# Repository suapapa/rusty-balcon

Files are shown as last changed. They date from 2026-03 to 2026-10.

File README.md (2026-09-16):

# Rusty Balcon

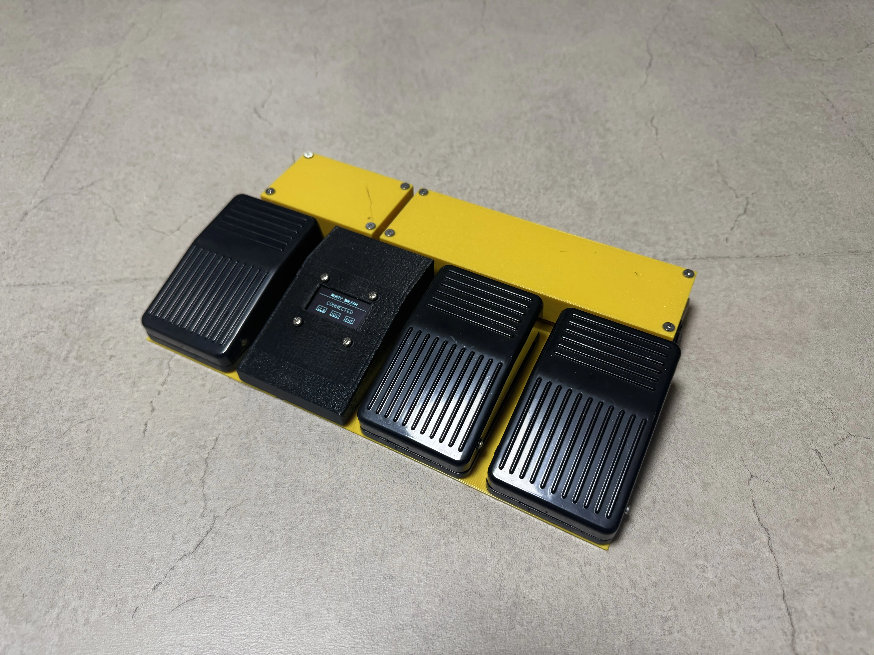
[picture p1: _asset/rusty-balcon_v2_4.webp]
Rusty Balcon


**Rusty Balcon** is a Rust-based firmware for an ESP32-H2 acting as a 3-key barebones Bluetooth (BLE) keyboard. It leverages the standard library (`std`) and `esp-idf-svc` for a robust development environment, implementing a HID Keyboard profile using the NimBLE stack via `esp32-nimble`.

## Hardware Build

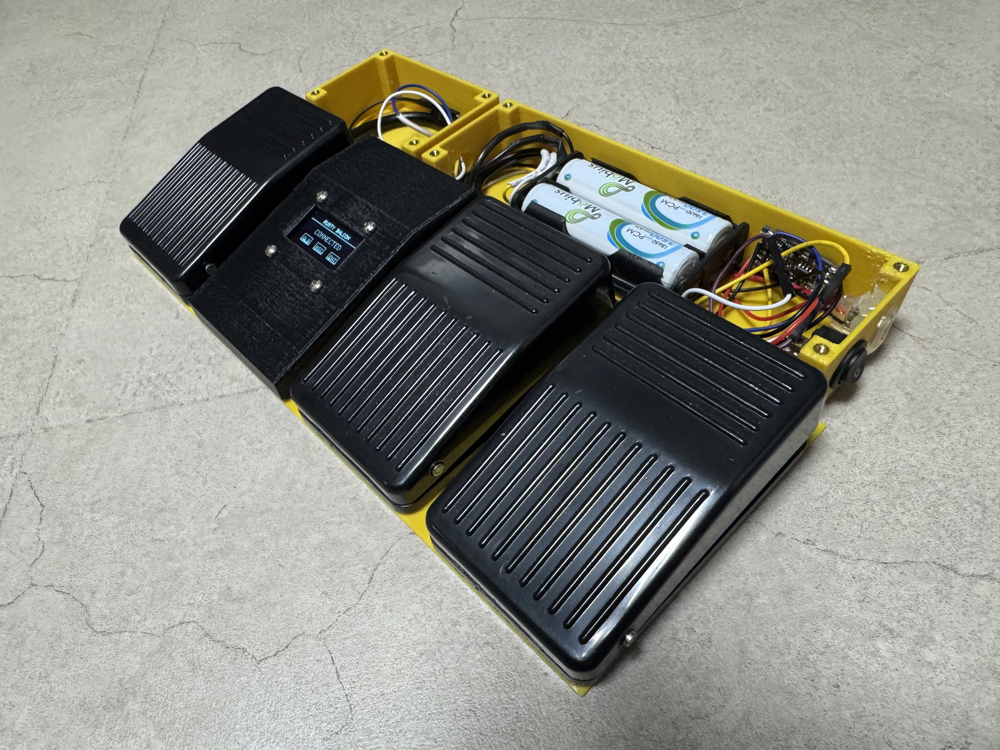
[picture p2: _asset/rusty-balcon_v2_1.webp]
Assembled build with internals

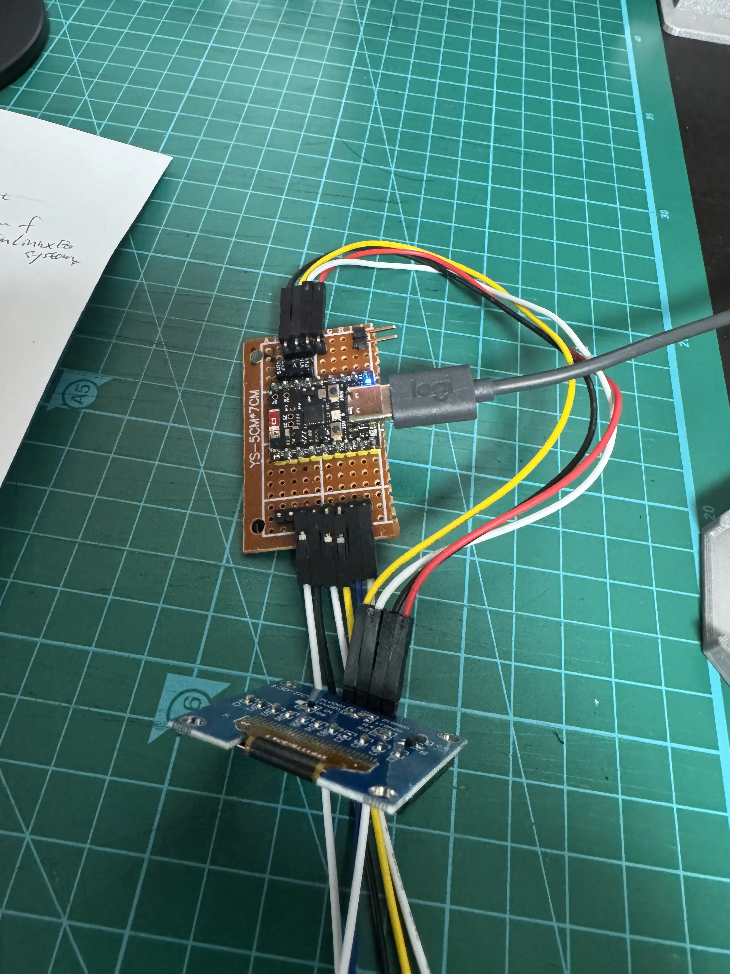
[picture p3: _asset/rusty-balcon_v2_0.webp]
Electronics prototype

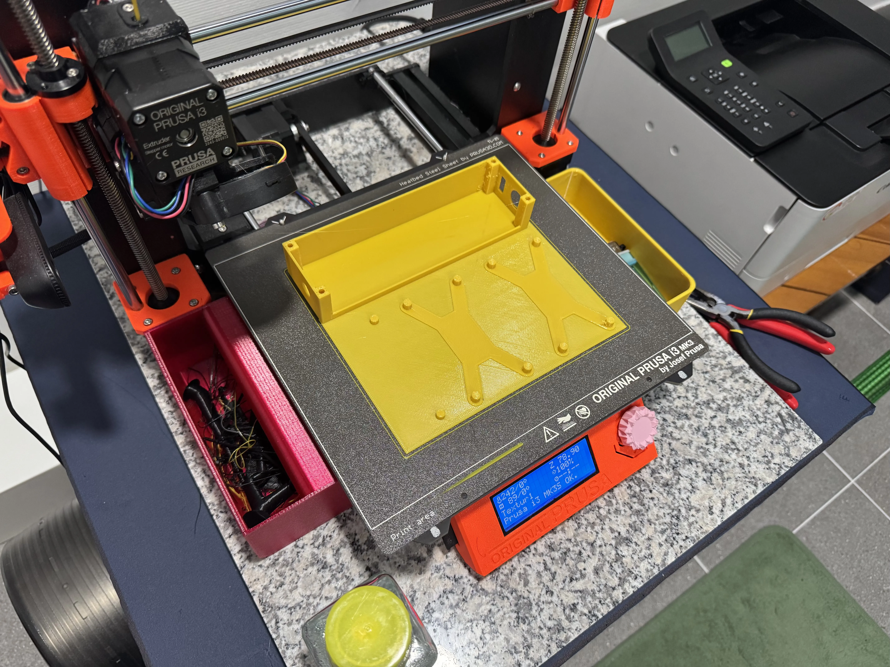
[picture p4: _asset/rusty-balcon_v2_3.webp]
3D-printed enclosure


## Hardware Configuration

- **Microcontroller**: ESP32-H2
  - Module reference: [esp32-h2-supermini-kicad](https://github.com/Zektopic/esp32-h2-supermini-kicad)
- **Inputs**: 3 Push Buttons (RTC GPIOs 7–14 required for deep-sleep EXT1 wakeup)
  - Key 1: `GPIO13` (Internal Pull-Up) → Globe 🌐 (Consumer AC Keyboard Layout Select)
  - Key 2: `GPIO11` (Internal Pull-Up) → Voice Command (Consumer Control) or Escape (ESC) Key (Toggleable)
  - Key 3: `GPIO12` (Internal Pull-Up) → Enter key
- **Display**: SH1106 128x64 OLED (I2C)
  - SDA: `GPIO4`
  - SCL: `GPIO5`

## Features

- **Bluetooth HID Keyboard**: Acts as a standard BLE keyboard using the NimBLE stack. Identifies as an Apple Magic Keyboard mock for best compatibility with macOS/iOS.
- **OLED Status Display**: Shows current device state on a 128x64 OLED screen with real-time key press visualization and dynamic Key 2 label (`MIC` / `ESC`).
- **Key 2 Mode Switching (Voice ↔ ESC)**: Hold **Key 1 (Globe) + Key 2** simultaneously for 5 seconds to toggle Key 2 function between **Voice Command (`MIC`)** and **Escape key (`ESC`)**. The selected mode is persisted to NVS (Non-Volatile Storage) across reboots and deep sleep.
- **Power Management**:
  - Display blanks after **30 seconds** of inactivity.
  - While **Connected**, stays awake (display off only) so keys remain instantly responsive.
  - Enters Deep Sleep after **30 minutes** of inactivity **only when Idle** (disconnected). Wakes on button press (GPIO13, GPIO11, or GPIO12 via EXT1).
- **Wakeup Key Replay**: The button press that wakes the device from deep sleep is remembered and automatically replayed 500ms after BLE reconnects (respecting the current Key 2 mode), so the keypress is never lost.
- **Pairing Mode**: Hold **Globe + Enter** simultaneously for 5 seconds to clear all bonds and enter pairing mode. OLED shows `>> PAIRING <<` while advertising for a new host.

## Device States

| Display Text | Meaning |
|---|---|
| `IDLE` | Not connected, advertising |
| `RECONNECTING...` | Woke from deep sleep, waiting for BLE to reconnect |
| `>> PAIRING <<` | Pairing mode active (blinking) |
| `CONNECTED` | Connected to a host |
| `MODE: VOICE` | Key 2 set to Voice Command (MIC) |
| `MODE: ESC` | Key 2 set to Escape (ESC) key |

## Prerequisites

- [Rust Toolchain](https://rustup.rs/) (1.88+)
- [espup](https://github.com/esp-rs/espup) for ESP-RS toolchain setup
- [ldproxy](https://github.com/esp-rs/ldproxy) for linking
- `espflash` for flashing: `cargo install espflash`

## Build and Run

1. **Environment Setup**: Ensure your ESP-IDF environment is sourced (e.g., `. $HOME/export-esp.sh`).
2. **Build**:
   ```bash
   cargo build --release
   ```
3. **Flash and Run**:
   ```bash
   cargo run --release
   ```

## License

This project is open-source and available under the MIT License.

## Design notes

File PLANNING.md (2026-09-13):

# 2-Key Bluetooth Keyboard Implementation Plan

## Overview
This document outlines the plan for building a 2-key Bluetooth (BLE) keyboard using the ESP32-H2 microcontroller, `esp-hal` (version `~1.0`), and the `bleps` Bluetooth stack. The firmware will manage key inputs, Bluetooth HID over GATT (HOGP) communication, LED status indication, and aggressive power saving via Deep Sleep.

## 1. Hardware Definition
- **MCU**: ESP32-H2 (configured via `cargo` and `esp-hal`).
- **Inputs**: 2 Push Buttons connected to RTC-capable GPIO pins to allow waking up from deep sleep. Keys should use internal pull-up resistors (`Input<'d, PullUp>`).
- **Outputs**: 1 LED connected to a standard output GPIO pin.
- **Power**: Battery-operated, necessitating power-saving states.

## 2. State Machine Design
The device operates in one of the following main states:
1. **Idle / Disconnected**: Device is awake but not connected or advertising. LED is OFF.
2. **Pairing Mode**: Activated by holding both keys for 5 seconds. BLE advertising begins. LED blinks synchronously.
3. **Connected**: Device successfully established a BLE connection with a host (PC/Phone). LED stays ON solidly.
4. **Deep Sleep**: Entered after 5 minutes of total inactivity to conserve battery. Device halts execution and waits for a hardware interrupt (RTC wakeup) to reboot.

## 3. Core Features & Implementation Details

### A. Key Input & Long-Press Detection
- Use non-blocking timers (`esp_hal::time::Instant`) to track button states instead of blocking delays.
- Track variables for when both keys were first depressed.
- If both buttons remain depressed continuously for `5000` milliseconds, trigger the transition to **Pairing Mode**.
- Reset the hold timer immediately if either button is released.

### B. LED Status Control
- **State: Pairing**: Implement a periodic blink (e.g., toggle every 500ms) comparing `Instant::now()` against a stored timestamp.
- **State: Connected**: Assert the GPIO high to keep the LED ON.
- **State: Deep Sleep / Idle**: De-assert the GPIO to keep the LED OFF.

### C. Bluetooth & HID functionality (`bleps`)
- **BLE Stack**: Utilize `esp_radio::init()` and `BleConnector::new()` as the transport layer for `bleps`.
- **GATT Attributes**: Configure standard BLE HID attributes:
  - **Device Information Service** (0x180A): Manufacturer, PnP ID.
  - **Battery Service** (0x180F): Optional, but highly recommended for battery devices.
  - **Human Interface Device Service** (0x1812): Host the HID Report Map (defining the device as a typical Keyboard) and characteristic endpoints for Input Reports.
- **Advertising**: Start advertising with "Discoverable" flags and the HID appearance UUID when Pairing Mode is active.
- **Event Handling**: On a valid keypress (in the Connected state), generate an HID Report array mapping the respective key to a standard USB usage code (e.g., `Enter` or `Space`), and notify the GATT characteristic. Send an empty report when the key is released.

### D. Deep Sleep & Battery Management
- Maintain a `last_activity` timestamp. Update this timestamp whenever:
  - A button state changes (press or release).
  - A BLE connection event occurs.
- Monitor `Instant::now().duration_since(last_activity)`. If this exceeds 5 minutes (300 seconds), prepare for sleep.
- **Entering Deep Sleep**:
  1. Gracefully terminate BLE connections.
  2. Turn off the LED.
  3. Configure the specific GPIO pins for the 2 keys as wakeup sources utilizing ESP32-H2's GPIO deep-sleep wakeup.
  4. Invoke `Rtc::sleep_deep()`. The MCU will power down and effectively reset upon the next key press.

## 4. Software Architecture Outline
Due to the presence of `bleps` with the `async` feature enabled, the architecture can neatly fit into an async executor loop or a fast concurrent polled loop.

```rust
// Draft Pseudocode Architecture
let mut state = State::Idle;
let mut last_activity = Instant::now();
let mut hold_start: Option<Instant> = None;

loop {
    let now = Instant::now();
    let k1_pressed = key1.is_low();
    let k2_pressed = key2.is_low();

    // 1. Inactivity Tracker
    if k1_pressed || k2_pressed /* or ble activity */ {
        last_activity = now;
    }

    // 2. Deep Sleep Transition
    if now.duration_since(last_activity) > Duration::from_secs(300) {
        // Setup RTC Wakeup for key1_pin and key2_pin
        // Enter deep sleep
    }

    // 3. 5-Second Hold detection
    if k1_pressed && k2_pressed {
        if let Some(start) = hold_start {
            if now.duration_since(start) >= Duration::from_secs(5) {
                state = State::Pairing;
                start_ble_advertising(); 
                hold_start = None; // Reset so it fires only once
            }
        } else {
            hold_start = Some(now);
        }
    } else {
        hold_start = None;
        
        // Handle normal key presses when connected
        if state == State::Connected {
            send_hid_report(k1_pressed, k2_pressed);
        }
    }

    // 4. LED & State Management
    match state {
        State::Idle => led.set_low(),
        State::Pairing => {
            // Blink LED every 500ms
            if (now.as_millis() / 500) % 2 == 0 {
                led.set_high();
            } else {
                led.set_low();
            }
            if ble_is_connected() {
                state = State::Connected;
            }
        },
        State::Connected => {
            led.set_high(); // Solid glow
            if !ble_is_connected() {
                state = State::Idle;
            }
        }
    }
    
    // 5. Yield/Process BLE Background Tasks
    // ble_executor.poll();
}
```

## Next Steps for Development
1. Define the explicit GPIO mappings for the ESP32-H2 in `main.rs`.
2. Construct the BLE HID Report Map for a standard keyboard in `bleps`.
3. Implement the timer-based state machine logic for debouncing and hold detection.
4. Implement the deep sleep logic using `esp_hal::rtc_cntl::Rtc`.

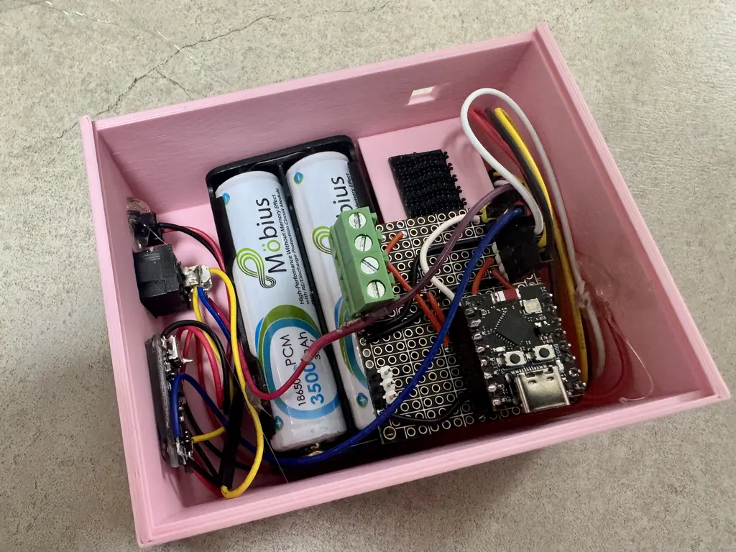
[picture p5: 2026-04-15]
_asset/rusty_balcon_02.webp

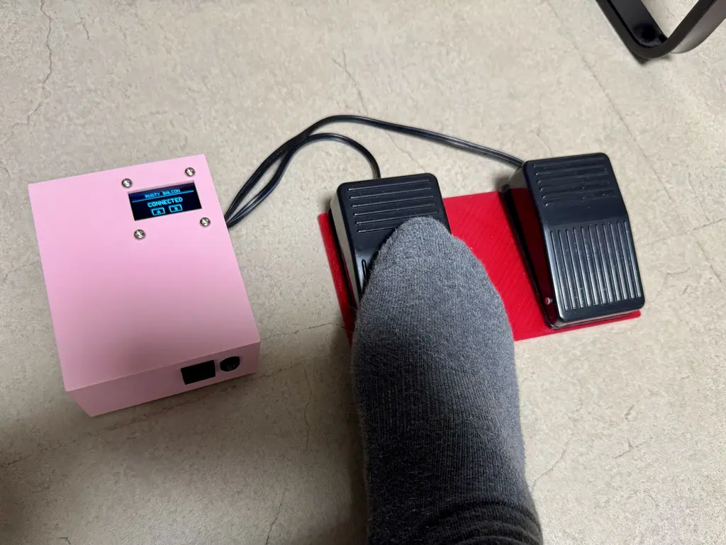
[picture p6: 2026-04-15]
_asset/rusty_balcon_01.webp

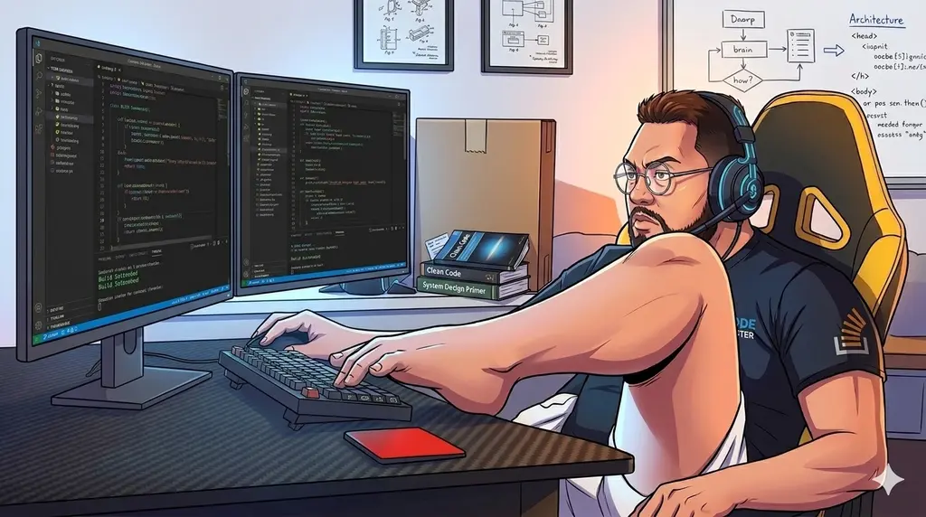
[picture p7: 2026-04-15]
_asset/rusty_balcon_00.webp

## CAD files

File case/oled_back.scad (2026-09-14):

oled_back();

module oled_back() {
    led_t=3;
    spt_t=6;
    hole_r=3;
    difference() {
        hull() {
            cylinder(spt_t,10/2,10/2,$fn=30);
            translate([0,29,0]) cylinder(spt_t,10/2,10/2,$fn=30);
        }
        translate([0,0,-0.5])cylinder(spt_t+1,hole_r/2,hole_r/2,$fn=10);
        translate([0,29,-0.5]) cylinder(spt_t+1,hole_r/2,hole_r/2,$fn=10);
        
        translate([-2.5,-2.5,spt_t-led_t-0.4]) cube(34);
        #translate([-2.5-3.5+2,-2.5+7,spt_t-led_t-1.5]) cube(20);
    }
}


module oled_front() {
    hw=33.8-3;
    hh=32-3;
    
    translate([-hw/2,0,0]) union() {
        cylinder(h=20, r=3.2/2, center=true, $fn=20);
        translate([hw, hh, 0]) cylinder(h=20, r=3.2/2, center=true, $fn=20);
        translate([hw, 0, 0]) cylinder(h=20, r=3.2/2, center=true, $fn=20);
        translate([0, hh, 0]) cylinder(h=20, r=3.2/2, center=true, $fn=20);
    }
    translate([-32/2,4,-10]) cube([32,17,20]);
}

module usb_c(){
    rotate([0,90,0]) union() {
        cube([13.5,5.5,20], center=true);
        cube([14,3.5,20], center=true);        
    }
}

module rotary_encoder() {
    rotate([0,90,0]) cylinder(h=20, r=7/2, center=true, $fn=20);
}

module shutter_jack() {
    rotate([0,90,0]) cylinder(h=20, r=7.2/2, center=true, $fn=20);
}

module switch() {
    rotate([0,90,0]) cylinder(h=20, r=6/2, center=true, $fn=20);
}

module pcb() {
    w=45;
    h=35;
    
    support(3,8);
    translate([w,h,0]) support(3,8);
    translate([0,h,0])support(3,8);
    translate([w,0,0])support(3,8);
}

module support(p,h) {
    difference() {
        cylinder(h=h, r=(p+3)/2);
        translate([0,0,-1]) cylinder(h=h+2, r=p/2);
    }
}

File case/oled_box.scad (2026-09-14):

difference() {
    pedal_box();
    rotate([15.95,0,0]) translate([0,65,0]) #oled();
    #bottom_holes();
}


module pedal_box() {
    // Shell: outer profile minus inner cavity (1.5mm walls), open at x=100 face
    H = 65;
    T = 1.5;

    translate([-H/2,0,0]) rotate([90,0,90])
    difference() {
        linear_extrude(height = H)
            polygon(points = [[0, 0], [0, -10], [100, -10], [100, 20], [70, 20]]);

        // cavity = outer profile offset inward by 1.5, extended past x=100 to open that face
        // hypotenuse (0,0)-(70,20) offset: 2x - 7y = 1.5*sqrt(53) ≈ 10.920
        translate([0,0,T]) linear_extrude(height = H-T*2)
            polygon(points = [
                [1.5, -1.1315],   // offset hypotenuse x offset x=1.5
                [1.5, -8.5],      // offset hypotenuse-> no: corner x=1.5 & y=-8.5
                [101.5, -8.5],    // past x=100 -> opens the face
                [101.5, 18.5],
                [70.2101, 18.5]   // offset hypotenuse x offset y=18.5
            ]);
    }
}


module oled() {
    hw=33.8-3;
    hh=32-3;
    
    rotate([0,0,180]) {
        translate([-hw/2,0,0]) union() {
            cylinder(h=20, r=3.2/2, center=true, $fn=20);
            translate([hw, hh, 0]) cylinder(h=20, r=3.2/2, center=true, $fn=20);
            translate([hw, 0, 0]) cylinder(h=20, r=3.2/2, center=true, $fn=20);
            translate([0, hh, 0]) cylinder(h=20, r=3.2/2, center=true, $fn=20);
        }
        translate([-32/2,4,-10]) cube([32,17,20]);
    }
}

module bottom_holes() {
    // w=50, h=80
    translate([25,10,-15]) cylinder(10, 3, 3);
    translate([-25,10,-15]) cylinder(10, 3, 3);
    translate([25,90,-15]) cylinder(10, 3, 3);
    translate([-25,90,-15]) cylinder(10, 3, 3);
}

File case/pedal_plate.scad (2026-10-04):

P=0; // 0: all, 1: left, 2: right


intersection() {
    if(P==0) {
        pedal_plate();
    } else if(P==1){
        intersection() {
            translate([-270-2,0,0])  cube(270);
            pedal_plate();
        }
    } else if(P==2){
        intersection() {
            translate([2,0,0])  cube(270);
            pedal_plate();
        }
    }
}

module pedal_plate() {
    translate([42.5,0,0]) {
        translate([-270/2,0,0]) cube([270, 110, 1]);

        translate([-70*2+70/2,0,0]) union(){
            pedal();
            translate([70,0,0]) control_box();
            translate([70*2,0,0]) pedal();
            translate([70*3,0,0]) pedal();
        }

        difference() {
            union() {
                translate([-65-20,100+25+5,0]) wire_box(L=80);
                translate([65-20,100+25+5,0]) wire_box(L=170);
            }
            #translate([0-20,125,15])rotate([0,90,0]) cylinder(h=70,r=5,center=true);
            #translate([125,125+15,15]) usb_c();
            #translate([125,125-3,15]) pwr_sw();
        }
    }
}

module pedal() {
    w = 40.4;   // 사각형 가로 (X)
    h = 80.8;   // 사각형 세로 (Y)
    r = 3;      // 실린더 반지름
    hgt = 7;    // 실린더 높이
    $fn = 12;
    translate([0,h/2+8,0]) {
        color("SteelBlue") {
            for (x = [-w/2, w/2], y = [-h/2, h/2]) {
                translate([x, y, 0])
                    cylinder(r = r, h = hgt);
            }
        
            hull() {
                translate([-w/2, -h/2, 0]) cylinder(r=r+2, h=2);
                translate([w/2, h/2, 0]) cylinder(r=r+2, h=2);
            }
            hull() {
                translate([-w/2, h/2, 0]) cylinder(r=r+2, h=2);
                translate([w/2, -h/2, 0]) cylinder(r=r+2, h=2);
            }
            
            translate([0,0,1]) cube([26,43,2], center=true);
        }
    }
}

module control_box() {
    r=3-0.1;
    color("SteelBlue") {
        translate([25,10,0]) cylinder(5, r, r);
        translate([-25,10,0]) cylinder(5, r, r);
        translate([25,90,0]) cylinder(5, r, r);
        translate([-25,90,0]) cylinder(5, r, r);
    }
}

module wire_box(L=125) {
    //L = 125;  // X
    W = 50;   // Y
    H = 30;   // Z
    t = 1.5;  // 두께

    difference() {
        translate([-L/2, -W/2, 0])
            cube([L, W, H]);
        translate([-L/2 + t, -W/2 + t, t])
            cube([L - 2*t, W - 2*t, H - t + 1]);
        translate([-L/2 + t, -W/2 + t-5, t+5])
            cube([L - 2*t, W - 2*t, H - t + 1]);
    }
    
    for (x = [-L/2+4, L/2-4], y = [-W/2+4, W/2-4]) {
        translate([x,y,0]) box_pilla(H);
    }

}

module box_pilla(H) {
    translate([0,0,H/2]) difference() {
        cube([8,8,H], center=true);
        cylinder(H, 2, 2, $fn=10);
    }
}

module usb_c(){
    rotate([0,90,0]) union() {
        cube([13.5,5.5,20], center=true);
        cube([14,3.5,20], center=true);        
    }
}

module pwr_sw() {
    rotate([90,0,0]) rotate([0,90,0]) union() {
        cylinder(h=20,r=15.2/2,center=true,$fn=20);
        cube([4,15.5,30],center=true);
    }
}

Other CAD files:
case/pedal_plate_box_lid.scad

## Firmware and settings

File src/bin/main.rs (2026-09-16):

use anyhow::Result;
use esp_idf_hal::delay::FreeRtos;
use esp_idf_hal::gpio::*;
use esp_idf_hal::i2c::*;
use esp_idf_hal::peripherals::Peripherals;
use esp_idf_hal::units::*;
use esp_idf_svc::eventloop::EspSystemEventLoop;
use esp_idf_svc::nvs::{EspDefaultNvsPartition, EspNvs};
use esp32_nimble::{BLEAdvertisementData, BLEDevice, BLEHIDDevice, NimbleProperties, enums::*};
use smart_leds::{RGB8, SmartLedsWrite};
use std::sync::{Arc, Mutex};
use std::time::{Duration, Instant};
use ws2812_esp32_rmt_driver::Ws2812Esp32Rmt;

use embedded_graphics::{
    mono_font::{
        MonoTextStyle, MonoTextStyleBuilder,
        ascii::{FONT_6X10, FONT_8X13},
    },
    pixelcolor::BinaryColor,
    prelude::*,
    primitives::{Line, PrimitiveStyle, Rectangle},
    text::{Alignment, Text},
};
use sh1106::Builder;
use sh1106::prelude::GraphicsMode;

mod config {
    use std::time::Duration;
    // Deep sleep only when Idle (not Connected). Keep BLE alive longer so keys respond immediately.
    pub const INACTIVITY_TIMEOUT: Duration = Duration::from_secs(1800); // 30 minutes
    pub const DISPLAY_TIMEOUT: Duration = Duration::from_secs(30); // 30 seconds
    pub const PAIRING_HOLD_DURATION: Duration = Duration::from_secs(5);
    pub const MODE_HOLD_DURATION: Duration = Duration::from_secs(5);
    pub const KEY_FLASH_DURATION: Duration = Duration::from_millis(80);
    pub const KEY_ENTER: u8 = 0x28; // Enter / Return
    pub const KEY_ESC: u8 = 0x29; // Escape
    // Keep onboard WS2812 dim — full white is a noticeable battery drain.
    pub const LED_KEY_WHITE: u8 = 48;
    pub const LED_PAIRING_BLUE: u8 = 40;
}

/// Blue heartbeat envelope: double-beat then rest, period 1.2s.
fn pairing_heartbeat_level(elapsed_ms: u128) -> u8 {
    let t = (elapsed_ms % 1200) as u32;
    let peak = config::LED_PAIRING_BLUE as u32;
    let envelope = |phase: u32, width: u32| -> u32 {
        if phase >= width {
            return 0;
        }
        // Triangle pulse
        let half = width / 2;
        if phase < half {
            phase * peak / half
        } else {
            (width - phase) * peak / half
        }
    };
    let level = match t {
        0..=149 => envelope(t, 150),
        150..=249 => 0,
        250..=369 => envelope(t - 250, 120) * 7 / 10, // softer second beat
        _ => 0,
    };
    level as u8
}

fn set_rgb_led(led: &mut Ws2812Esp32Rmt<'_>, color: RGB8) {
    let _ = led.write(std::iter::once(color));
}

#[derive(PartialEq, Eq, Clone, Copy, Debug)]
pub enum Key2Mode {
    Voice,
    Esc,
}

impl Key2Mode {
    pub fn label(&self) -> &'static str {
        match self {
            Key2Mode::Voice => "MIC",
            Key2Mode::Esc => "ESC",
        }
    }

    pub fn toggle(&self) -> Self {
        match self {
            Key2Mode::Voice => Key2Mode::Esc,
            Key2Mode::Esc => Key2Mode::Voice,
        }
    }

    pub fn to_u8(&self) -> u8 {
        match self {
            Key2Mode::Voice => 0,
            Key2Mode::Esc => 1,
        }
    }

    pub fn from_u8(val: u8) -> Self {
        match val {
            1 => Key2Mode::Esc,
            _ => Key2Mode::Voice,
        }
    }
}

mod hid {
    pub const REPORT_DESCRIPTOR: &[u8] = &[
        // Keyboard Report (ID 1)
        0x05, 0x01, 0x09, 0x06, 0xa1, 0x01, 0x85, 0x01, 0x05, 0x07, 0x19, 0xe0, 0x29, 0xe7, 0x15,
        0x00, 0x25, 0x01, 0x75, 0x01, 0x95, 0x08, 0x81, 0x02, 0x95, 0x01, 0x75, 0x08, 0x81, 0x01,
        0x05, 0x07, 0x19, 0x00, 0x29, 0x65, 0x15, 0x00, 0x25, 0x65, 0x75, 0x08, 0x95, 0x06, 0x81,
        0x00, 0xc0, // End Collection (keyboard)
        // Consumer Control Report (ID 2)
        // bit0: Voice Command (0xCF), bit1: Globe / AC Keyboard Layout Select (0x029D)
        0x05, 0x0c, 0x09, 0x01, 0xa1, 0x01, 0x85, 0x02, 0x15, 0x00, 0x25, 0x01, 0x75, 0x01, 0x95,
        0x02, 0x09, 0xcf, 0x0a, 0x9d, 0x02, 0x81, 0x02, 0x75, 0x01, 0x95, 0x06, 0x81, 0x03, 0xc0,
    ];

    pub fn create_keyboard_report(enter_pressed: bool, esc_pressed: bool) -> [u8; 8] {
        let mut report = [0u8; 8];
        let mut idx = 2;
        if enter_pressed {
            report[idx] = crate::config::KEY_ENTER;
            idx += 1;
        }
        if esc_pressed {
            report[idx] = crate::config::KEY_ESC;
        }
        report
    }

    pub fn create_consumer_report(globe_pressed: bool, voice_pressed: bool) -> [u8; 1] {
        let mut bits = 0u8;
        if voice_pressed {
            bits |= 1 << 0; // Voice Command (0xCF)
        }
        if globe_pressed {
            bits |= 1 << 1; // Globe (0x029D)
        }
        [bits]
    }
}

#[derive(PartialEq, Clone, Copy, Debug)]
enum MachineState {
    Idle,
    Pairing,
    Connected,
}

fn main() -> Result<()> {
    esp_idf_sys::link_patches();
    esp_idf_svc::log::EspLogger::initialize_default();

    // Suppress verbose NimBLE/GATT info logs
    unsafe {
        let tag = std::ffi::CString::new("NimBLE").unwrap();
        esp_idf_sys::esp_log_level_set(tag.as_ptr(), esp_idf_sys::esp_log_level_t_ESP_LOG_WARN);
    }

    // ESP32-H2 EXT1 wakeup GPIOs are RTC IOs 7–14. Keys use GPIO13 / GPIO11 / GPIO12.
    const KEY1_GPIO: u32 = 13;
    const KEY2_GPIO: u32 = 11;
    const KEY3_GPIO: u32 = 12;

    // Check wakeup cause before taking peripherals (must be called early)
    let wakeup_gpio_status: u64 = unsafe {
        let cause = esp_idf_sys::esp_sleep_get_wakeup_cause();
        if cause == esp_idf_sys::esp_sleep_source_t_ESP_SLEEP_WAKEUP_EXT1 {
            esp_idf_sys::esp_sleep_get_ext1_wakeup_status()
        } else {
            0
        }
    };
    let wakeup_pending: Option<(bool, bool, bool)> = if wakeup_gpio_status != 0 {
        Some((
            (wakeup_gpio_status & (1 << KEY1_GPIO)) != 0,
            (wakeup_gpio_status & (1 << KEY2_GPIO)) != 0,
            (wakeup_gpio_status & (1 << KEY3_GPIO)) != 0,
        ))
    } else {
        None
    };

    let peripherals = Peripherals::take().unwrap();
    let _sysloop = EspSystemEventLoop::take()?;
    let nvs_default = EspDefaultNvsPartition::take()?;
    let mut nvs = match EspNvs::new(nvs_default, "config", true) {
        Ok(nvs) => Some(nvs),
        Err(e) => {
            println!("Failed to initialize NVS: {:?}", e);
            None
        }
    };

    let mut key2_mode = if let Some(nvs) = &nvs {
        match nvs.get_u8("k2_mode") {
            Ok(Some(val)) => Key2Mode::from_u8(val),
            Ok(None) => Key2Mode::Voice,
            Err(e) => {
                println!("Failed to read k2_mode from NVS: {:?}", e);
                Key2Mode::Voice
            }
        }
    } else {
        Key2Mode::Voice
    };
    println!("Initial Key 2 Mode: {:?}", key2_mode);

    // GPIO Setup (RTC-capable pins required for deep-sleep EXT1 wakeup)
    let key1 = PinDriver::input(peripherals.pins.gpio13, Pull::Up)?;
    let key2 = PinDriver::input(peripherals.pins.gpio11, Pull::Up)?;
    let key3 = PinDriver::input(peripherals.pins.gpio12, Pull::Up)?;

    // Onboard WS2812 RGB LED (ESP32-H2 SuperMini → GPIO8)
    // ws2812-esp32-rmt-driver 0.14 still uses the legacy RMT channel API.
    #[allow(deprecated)]
    let mut rgb_led = Ws2812Esp32Rmt::new(peripherals.rmt.channel0, peripherals.pins.gpio8)?;
    set_rgb_led(&mut rgb_led, RGB8::new(0, 0, 0));

    // I2C & Display Setup
    let sda = peripherals.pins.gpio4;
    let scl = peripherals.pins.gpio5;
    let i2c_config = I2cConfig::new().baudrate(100u32.kHz().into());
    let i2c_driver = I2cDriver::new(peripherals.i2c0, sda, scl, &i2c_config)?;

    let mut display: GraphicsMode<_> = Builder::new().connect_i2c(i2c_driver).into();

    display.init().unwrap_or_else(|e| {
        println!("Display init error: {:?}", e);
    });
    let _ = display.set_contrast(0x10); // Dim the display to save power
    let _ = display.clear();
    let welcome_style = MonoTextStyle::new(&FONT_8X13, BinaryColor::On);
    let tag_style = MonoTextStyle::new(&FONT_6X10, BinaryColor::On);

    let _ = Text::with_alignment(
        "RUSTY BALCON",
        Point::new(64, 30),
        welcome_style,
        Alignment::Center,
    )
    .draw(&mut display);
    let _ = Text::with_alignment(
        env!("GIT_TAG"),
        Point::new(64, 45),
        tag_style,
        Alignment::Center,
    )
    .draw(&mut display);
    let _ = display.flush();
    FreeRtos::delay_ms(1500);

    // BLE Setup
    let _ = BLEDevice::set_device_name("Rusty-Balcon");
    let device = BLEDevice::take();
    device
        .security()
        .set_auth(AuthReq::all())
        .set_io_cap(SecurityIOCap::NoInputNoOutput)
        .resolve_rpa();

    let server = device.get_server();

    // Mandatory for macOS/iOS HID: Device Info Service
    let info_service = server.create_service(esp32_nimble::utilities::BleUuid::from_uuid16(0x180A));
    info_service
        .lock()
        .create_characteristic(
            esp32_nimble::utilities::BleUuid::from_uuid16(0x2A29),
            NimbleProperties::READ,
        )
        .lock()
        .set_value(b"Rusty-Balcon Team");
    info_service
        .lock()
        .create_characteristic(
            esp32_nimble::utilities::BleUuid::from_uuid16(0x2A24),
            NimbleProperties::READ,
        )
        .lock()
        .set_value(b"RB-01");

    // Battery Service (Ensures macOS sees it as a proper peripheral)
    let battery_service =
        server.create_service(esp32_nimble::utilities::BleUuid::from_uuid16(0x180F));
    battery_service
        .lock()
        .create_characteristic(
            esp32_nimble::utilities::BleUuid::from_uuid16(0x2A19),
            NimbleProperties::READ | NimbleProperties::READ_ENC | NimbleProperties::NOTIFY,
        )
        .lock()
        .set_value(&[100]);

    let mut hid = BLEHIDDevice::new(server);
    hid.report_map(hid::REPORT_DESCRIPTOR);
    hid.pnp(0x02, 0x05ac, 0x820a, 0x0210); // Apple Magic Keyboard mock
    hid.set_battery_level(100);

    let keyboard_report = hid.input_report(1);
    let consumer_report = hid.input_report(2);

    let advertising = device.get_advertising();
    let mut ad_data = BLEAdvertisementData::new();
    ad_data
        .name("Rusty-Balcon")
        .appearance(0x03C1) // Keyboard
        .add_service_uuid(esp32_nimble::utilities::BleUuid::from_uuid16(0x1812));
    advertising.lock().set_data(&mut ad_data)?;
    println!("Starting advertising on boot...");
    if let Err(e) = advertising.lock().start() {
        println!("Failed to start advertising: {:?}", e);
    }

    let mut state = MachineState::Idle;
    let server_arc = Arc::new(Mutex::new(MachineState::Idle));
    let server_arc_clone = server_arc.clone();

    server.on_connect(move |server, desc| {
        println!("BLE Connected: {:?}", desc);
        let mut s = server_arc_clone.lock().unwrap();
        *s = MachineState::Connected;

        // macOS prefers specific connection parameters for HID
        if let Err(e) = server.update_conn_params(desc.conn_handle(), 12, 12, 0, 400) {
            println!("Failed to update conn params: {:?}", e);
        }
    });

    let server_arc_clone2 = server_arc.clone();
    server.on_disconnect(move |desc, reason| {
        println!("BLE Disconnected: {:?}, reason: {:?}", desc, reason);
        let mut s = server_arc_clone2.lock().unwrap();
        *s = MachineState::Idle;
    });

    let mut last_activity = Instant::now();
    let mut pairing_hold_start: Option<Instant> = None;
    let mut mode_hold_start: Option<Instant> = None;
    let mut mode_hold_triggered = false;
    let mut mode_toast_until: Option<Instant> = None;
    let mut last_display_state = (MachineState::Idle, true, true, true, Key2Mode::Voice, true, false); // Force initial draw
    let mut last_kb_report = [0u8; 8];
    let mut last_cons_report = [0u8; 1];
    let mut display_is_on = true;
    let blink_timer = Instant::now();
    let mut wakeup_key_to_send = wakeup_pending; // pending key from deep sleep wakeup
    let mut connect_time: Option<Instant> = None; // time of last BLE connection
    let mut prev_any_key = false;
    let mut key_flash_until: Option<Instant> = None;
    let mut last_led_color = RGB8::new(0, 0, 0);

    loop {
        let now = Instant::now();
        let k1_p = key1.is_low();
        let k2_p = key2.is_low();
        let k3_p = key3.is_low();

        let new_state = *server_arc.lock().unwrap();
        if new_state != state {
            println!("State changed: {:?} -> {:?}", state, new_state);
            if new_state == MachineState::Connected {
                connect_time = Some(now);
            }
            state = new_state;
        }

        if k1_p || k2_p || k3_p {
            last_activity = now;
        }

        // White flash on any key press edge (same for all keys)
        let any_key = k1_p || k2_p || k3_p;
        if any_key && !prev_any_key {
            key_flash_until = Some(now + config::KEY_FLASH_DURATION);
        }
        prev_any_key = any_key;

        // Status LED: key flash > pairing heartbeat > off
        let led_color = if key_flash_until.is_some_and(|until| now < until) {
            let w = config::LED_KEY_WHITE;
            RGB8::new(w, w, w)
        } else {
            key_flash_until = None;
            if state == MachineState::Pairing {
                let level = pairing_heartbeat_level(now.duration_since(blink_timer).as_millis());
                RGB8::new(0, 0, level)
            } else {
                RGB8::new(0, 0, 0)
            }
        };
        // Heartbeat needs frequent writes; otherwise only update on change.
        let force_led_update = state == MachineState::Pairing && key_flash_until.is_none();
        if force_led_update || led_color != last_led_color {
            set_rgb_led(&mut rgb_led, led_color);
            last_led_color = led_color;
        }

        // Deep sleep only when Idle + inactive. Stay awake while Connected so BLE stays hot.
        if state == MachineState::Idle
            && now.duration_since(last_activity) >= config::INACTIVITY_TIMEOUT
        {
            println!("No activity for 30m while Idle. Entering deep sleep...");
            set_rgb_led(&mut rgb_led, RGB8::new(0, 0, 0));
            let _ = display.clear();
            let _ = display.flush();
            FreeRtos::delay_ms(100);

            unsafe {
                // Wake on GPIO13 / GPIO11 / GPIO12 low (ESP32-H2 EXT1 / RTC IO 7–14)
                const WAKEUP_PIN_MASK: u64 =
                    (1 << KEY1_GPIO) | (1 << KEY2_GPIO) | (1 << KEY3_GPIO);
                esp_idf_sys::esp_sleep_enable_ext1_wakeup(
                    WAKEUP_PIN_MASK,
                    esp_idf_sys::esp_sleep_ext1_wakeup_mode_t_ESP_EXT1_WAKEUP_ANY_LOW,
                );
                esp_idf_sys::esp_deep_sleep_start();
            }
        }

        // Key 2 Mode Toggle (Hold Key 1 + Key 2 for 5s)
        if k1_p && k2_p && !k3_p {
            if !mode_hold_triggered {
                if let Some(start) = mode_hold_start {
                    if now.duration_since(start) >= config::MODE_HOLD_DURATION {
                        key2_mode = key2_mode.toggle();
                        println!("Key 2 Mode changed to: {:?}", key2_mode);
                        if let Some(nvs) = &mut nvs {
                            if let Err(e) = nvs.set_u8("k2_mode", key2_mode.to_u8()) {
                                println!("Failed to save k2_mode to NVS: {:?}", e);
                            }
                        }
                        mode_hold_triggered = true;
                        mode_toast_until = Some(now + Duration::from_secs(2));
                        key_flash_until = Some(now + Duration::from_millis(300));

                        // Release any currently pressed key reports immediately
                        if state == MachineState::Connected {
                            keyboard_report.lock().set_value(&[0u8; 8]);
                            keyboard_report.lock().notify();
                            consumer_report.lock().set_value(&[0u8; 1]);
                            consumer_report.lock().notify();
                            last_kb_report = [0u8; 8];
                            last_cons_report = [0u8; 1];
                        }
                    }
                } else {
                    mode_hold_start = Some(now);
                }
            }
        } else {
            mode_hold_start = None;
            mode_hold_triggered = false;
        }

        // Pairing Toggle (Hold Key 1 + Key 3 for 5s)
        if k1_p && k3_p && !k2_p {
            if let Some(start) = pairing_hold_start {
                if now.duration_since(start) >= config::PAIRING_HOLD_DURATION {
                    if state != MachineState::Pairing {
                        println!("Manual Pairing Start (Clearing all bonds)...");
                        unsafe {
                            esp_idf_sys::ble_store_clear();
                        }
                        if let Err(e) = advertising.lock().start() {
                            println!("Failed to start pairing advertising: {:?}", e);
                        }
                        let mut s = server_arc.lock().unwrap();
                        *s = MachineState::Pairing;
                    }
                }
            } else {
                pairing_hold_start = Some(now);
            }
        } else {
            pairing_hold_start = None;
        }

        // Display Power Management
        let inactivity_duration = now.duration_since(last_activity);
        let is_mode_toast = mode_toast_until.is_some_and(|until| now < until);
        let target_display_on = state == MachineState::Pairing
            || inactivity_duration < config::DISPLAY_TIMEOUT
            || is_mode_toast;

        if target_display_on != display_is_on {
            if target_display_on {
                let _ = display.set_contrast(0x10);
            } else {
                let _ = display.set_contrast(0);
                let _ = display.clear();
                let _ = display.flush();
            }
            display_is_on = target_display_on;
            if display_is_on {
                // Force redraw when turning back on
                last_display_state = (MachineState::Idle, true, true, true, Key2Mode::Voice, true, false);
            }
        }

        // Update Display
        let is_pairing_blink = state == MachineState::Pairing
            && (now.duration_since(blink_timer).as_millis() % 1000 < 500);
        let is_reconnecting = wakeup_key_to_send.is_some();
        let current_display_state = (
            state,
            k1_p,
            k2_p,
            k3_p,
            key2_mode,
            is_pairing_blink || is_reconnecting,
            is_mode_toast,
        );

        if display_is_on && current_display_state != last_display_state {
            let _ = display.clear();

            let header_style = MonoTextStyle::new(&FONT_6X10, BinaryColor::On);
            let status_style = MonoTextStyle::new(&FONT_8X13, BinaryColor::On);

            // App Title
            let _ = Text::with_alignment(
                "RUSTY BALCON",
                Point::new(64, 10),
                header_style,
                Alignment::Center,
            )
            .draw(&mut display);

            // Separator Line
            let _ = Line::new(Point::new(0, 14), Point::new(127, 14))
                .into_styled(PrimitiveStyle::with_stroke(BinaryColor::On, 1))
                .draw(&mut display);

            // Connection Status
            let status_text = if is_mode_toast {
                match key2_mode {
                    Key2Mode::Voice => "MODE: VOICE",
                    Key2Mode::Esc => "MODE: ESC",
                }
            } else {
                match state {
                    MachineState::Idle => {
                        if wakeup_key_to_send.is_some() {
                            "RECONNECTING..."
                        } else {
                            "IDLE"
                        }
                    }
                    MachineState::Pairing => {
                        if is_pairing_blink {
                            ">> PAIRING <<"
                        } else {
                            "-- PAIRING --"
                        }
                    }
                    MachineState::Connected => "CONNECTED",
                }
            };
            let _ = Text::with_alignment(
                status_text,
                Point::new(64, 33),
                status_style,
                Alignment::Center,
            )
            .draw(&mut display);

            // Key Visualization Boxes
            let key_width = 24u32;
            let key_height = 14u32;
            let key_y = 42i32;
            let key_xs = [14i32, 52, 90];
            let key_labels = ["GLB", key2_mode.label(), "ENT"];
            let key_pressed = [k1_p, k2_p, k3_p];

            for i in 0..3 {
                let x = key_xs[i];
                let pressed = key_pressed[i];
                let rect = Rectangle::new(Point::new(x, key_y), Size::new(key_width, key_height));
                let style = if pressed {
                    PrimitiveStyle::with_fill(BinaryColor::On)
                } else {
                    PrimitiveStyle::with_stroke(BinaryColor::On, 1)
                };
                let _ = rect.into_styled(style).draw(&mut display);
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

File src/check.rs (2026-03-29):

#![no_std]
#![no_main]

use esp_hal::gpio::{Input, InputConfig, Pull, RtcPinWithResistors};
use esp_hal::rtc_cntl::sleep::{RtcioWakeupSource, WakeupLevel, TimerWakeupSource};
use esp_hal::rtc_cntl::Rtc;

#[panic_handler]
fn panic(_: &core::panic::PanicInfo) -> ! { loop {} }

#[esp_hal::main]
fn main() -> ! {
    let peripherals = esp_hal::init(esp_hal::Config::default());
    let mut rtc = Rtc::new(peripherals.LPWR);
    let mut gpio2 = peripherals.GPIO2;
    let mut gpio3 = peripherals.GPIO3;

    let key1 = Input::new(gpio2.reborrow(), InputConfig::default().with_pull(Pull::Up));
    let key2 = Input::new(gpio3.reborrow(), InputConfig::default().with_pull(Pull::Up));

    let timer = TimerWakeupSource::new(core::time::Duration::from_secs(10));

    core::mem::drop(key1);
    core::mem::drop(key2);

    let wakeup_pins: &mut [(&mut dyn RtcPinWithResistors, WakeupLevel)] = &mut [
        (&mut gpio2, WakeupLevel::Low),
        (&mut gpio3, WakeupLevel::Low),
    ];
    let rtcio = RtcioWakeupSource::new(wakeup_pins);

    rtc.sleep_deep(&[&timer, &rtcio]);
}

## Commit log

2026-03-29 feat: setup project documentation and fix build configuration
    - Add README.md with project overview, hardware details, and build instructions
    - Add AGENTS.md for AI agent instructions and workflow guidelines
    - Add PLANNING.md for architectural and state machine details
    - Move check.rs out of src/bin to prevent cargo auto-discovery build failures
    - Update firmware main and project dependencies
    [check.rs, main.rs]
2026-03-29 refactor: improve HID reporting logic and project configuration
    - Refactor HID report handling in main.rs to use a state flag, preventing redundant release notifications.
    - Simplify state machine logic and standardize Result/Option types.
    - Update .gitignore with standard Rust and ESP-specific patterns.
    - Disable tests for the main binary in Cargo.toml.
    [main.rs]
2026-04-01 feat: migrate to std with esp-idf-svc and esp32-nimble
    - Replace bleps/no_std with esp32-nimble and std ecosystem
    - Update project configuration for riscv32imc-esp-espidf
    - Implement 2-key HID Keyboard with NimBLE
    - Add pairing mode and deep sleep support
    - Update documentation (README, AGENTS.md)
    [main.rs]
2026-04-01 fix: improve macOS/iOS HID compatibility and stability
    - Implement manual Battery and Device Information Services
    - Set secure characteristic properties to trigger bonding
    - Explicitly set GAP device name to fix 'nimble' display
    - Optimize GATT connection parameters for macOS
    - Suppress verbose NimBLE logging
    [main.rs]
2026-04-01 chore: release v0.1.0 - SH1106 fix, auto-reconnect, and pairing improvements
    [main.rs]
2026-04-04 feat: add consumer control for voice command on KEY_B and map KEY_A to ESC
2026-04-07 Feat: Display current git tag version on OLED
2026-04-12 feat: optimize battery power consumption
    - Enable automatic power management (light sleep) in ESP-IDF
    - Reduce OLED contrast and implement 30s display timeout
    - Reduce inactivity timeout to 5 minutes for deep sleep
    - Lower FreeRTOS tick rate to 100Hz to reduce overhead
2026-04-15 fix: replay wakeup key press after BLE reconnects from deep sleep
    When the device wakes from deep sleep via GPIO button press, it reboots
    and the button press that triggered the wakeup is lost if BLE hasn't
    reconnected yet. This fix captures which GPIO(s) caused the wakeup at
    boot time and replays the corresponding key press/release event 500ms
    after BLE reconnects.
    Also displays "RECONNECTING..." on OLED (instead of "IDLE") while
    waiting for the host to reconnect after a deep sleep wakeup.
    [main.rs]
2026-09-13 Migrate target architecture from ESP32-C3 to ESP32-H2
2026-09-13 Update pin mapping and pairing shortcut
    [main.rs]
2026-09-13 Add WS2812 RGB LED support for status and key feedback
2026-09-13 Replace ESC key with Globe consumer control key
    [main.rs]
2026-09-14 add case
    [pedal_box.scad, pedal_box_led_back.scad, pedal_plate.scad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]
2026-09-16 Update pedal plate and box designs in OpenSCAD
    [pedal_plate.scad, pedal_plate.stl, pedal_plate_box_lid.scad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]
2026-09-16 Add toggleable mode for Key 2
    Introduce a toggleable mode for Key 2, allowing it to switch between
    Voice Command (MIC) and Escape (ESC).
    - Implement mode switching by holding Key 1 and Key 2 for 5 seconds
    - Persist selected mode to NVS to survive reboots and deep sleep
    - Update OLED to show current mode and dynamic key labels
    - Adjust wakeup key replay logic to respect the active Key 2 mode
    [main.rs]
2026-09-27 Rename pedal box files to reflect LED functionality
    Rename pedal box OpenSCAD files to pedal_led_box and add
    corresponding STL files. Remove unused pedal plate files.
    [pedal_led_box.scad, pedal_led_box.stl, pedal_led_box_back.scad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]
2026-10-04 Update pedal plate models and rename OLED box files
    [oled_back.scad, oled_box.scad, pedal_led_box.stl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]
